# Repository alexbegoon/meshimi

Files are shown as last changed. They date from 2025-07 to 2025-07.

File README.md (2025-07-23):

<div align="center" markdown="1">

<h1>Meshimi</h1>

<b>Open Hardware & Open Source Multi-Protocol Wireless Module</b>

</div>

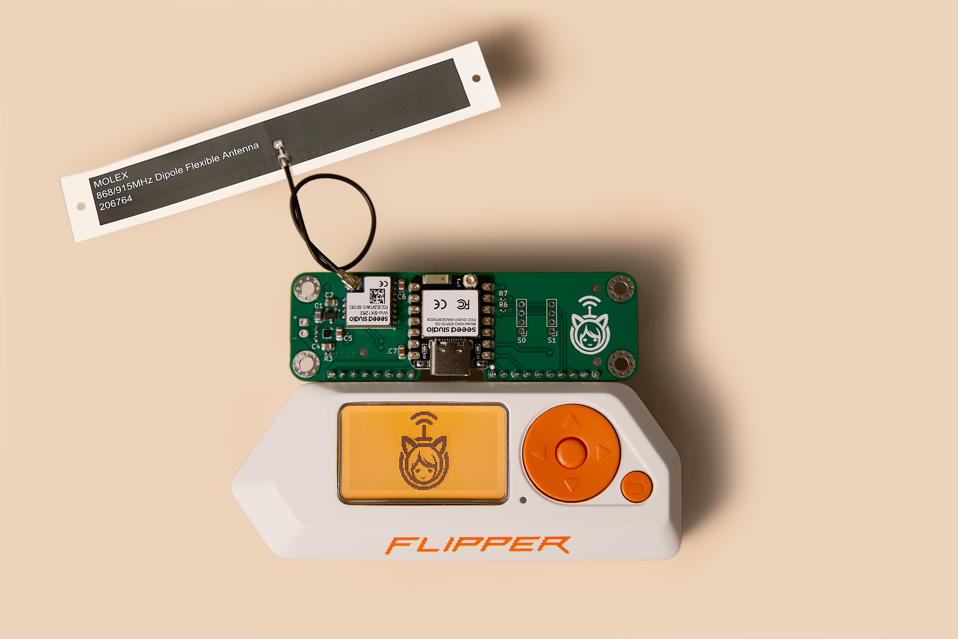
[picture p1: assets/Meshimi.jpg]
Meshimi


Meshimi empowers your Flipper Zero with advanced mesh networking capabilities, utilizing Meshtastic, LoRaWAN, WiFi6 and Bluetooth protocols.



## 📁 Repository Structure
- [`hardware/`](hardware) - PCB schematics, layouts, and production files
- [`mechanical/`](mechanical) - 3D models, enclosures, and assembly guides
- [`firmware/`](firmware) - Core firmware and code examples
- [`software/`](software) - Flipper Zero app and configuration tools
- [`documentation/`](documentation) - Documentation, guides, and certifications
- [`assets/`](assets) - Logos, photos, and marketing materials

## 📖 Documentation

### 🛡️ Certifications
Meshimi project utilizes pre-certified RF modules to ensure regulatory compliance. 
The corresponding CE, FCC, and other certification documentation for these modules are available 
in the [certifications](documentation/certifications) directory. 

We are committed to maintaining full regulatory compliance.

_Seeed XIAO ESP32-C6 module_ is used in Meshimi, which has the following certifications:

1. [Seeed-XIAO-ESP32C6-CE-Verification.pdf](documentation/certifications/Seeed-XIAO-ESP32C6-CE-Verification.pdf)

2. [Seeed-XIAO-ESP32C6-EU-Declaration.pdf](documentation/certifications/Seeed-XIAO-ESP32C6-EU-Declaration.pdf)

3. [Seeed-XIAO-ESP32C6-FCC-Declaration.pdf](documentation/certifications/Seeed-XIAO-ESP32C6-FCC-Declaration.pdf)

4. [Seeed-XIAO-ESP32C6-TELEC-Certificate.pdf](documentation/certifications/Seeed-XIAO-ESP32C6-TELEC-Certificate.pdf)

5. [Seeed-XIAO-ESP32C6-UK-Declaration.pdf](documentation/certifications/Seeed-XIAO-ESP32C6-UK-Declaration.pdf)

6. [Seeed-XIAO-Series-RoHS-Certificate.pdf](documentation/certifications/Seeed-XIAO-Series-RoHS-Certificate.pdf)

_Seeed Wio SX-1262 module_ is used in Meshimi, which has the following certifications:

1. [Seeed-Wio-SX1262-CE-Verification.pdf](documentation/certifications/Seeed-Wio-SX1262-CE-Verification.pdf)

2. [Seeed-Wio-SX1262-EU-Declaration.pdf](documentation/certifications/Seeed-Wio-SX1262-EU-Declaration.pdf)

3. [Seeed-Wio-SX1262-FCC-Authorization.pdf](documentation/certifications/Seeed-Wio-SX1262-FCC-Authorization.pdf)

4. [Seeed-Wio-SX1262-TELEC-Certificate.pdf](documentation/certifications/Seeed-Wio-SX1262-TELEC-Certificate.pdf)

5. [Seeed-Wio-SX1262-UK-Declaration.pdf](documentation/certifications/Seeed-Wio-SX1262-UK-Declaration.pdf)

6. [Seeed-Wio-SX1262-RoHS-Certificate.pdf](documentation/certifications/Seeed-Wio-SX1262-RoHS-Certificate.pdf)

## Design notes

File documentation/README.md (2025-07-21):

## Documentation

#### Index
1. [Enclosures for the Meshimi Module](enclosure.md)
2. [Flipper Zero user guide](flipper.md)

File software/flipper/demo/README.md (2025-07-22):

# Meshimi

Meshimi unlocks powerful mesh networking for your [Flipper Zero](https://flipperzero.one/) combining [Meshtastic](https://meshtastic.org/), [LoRaWAN](https://lora-alliance.org/about-lorawan/) and other protocols like [Matter](https://developers.home.google.com/matter/overview) and [Thread](https://www.threadgroup.org/What-is-Thread/Overview) to give you rock‑solid connectivity across miles, even off‑grid.

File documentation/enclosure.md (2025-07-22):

## Enclosures for the Meshimi Module



### Design with Built-in Antenna

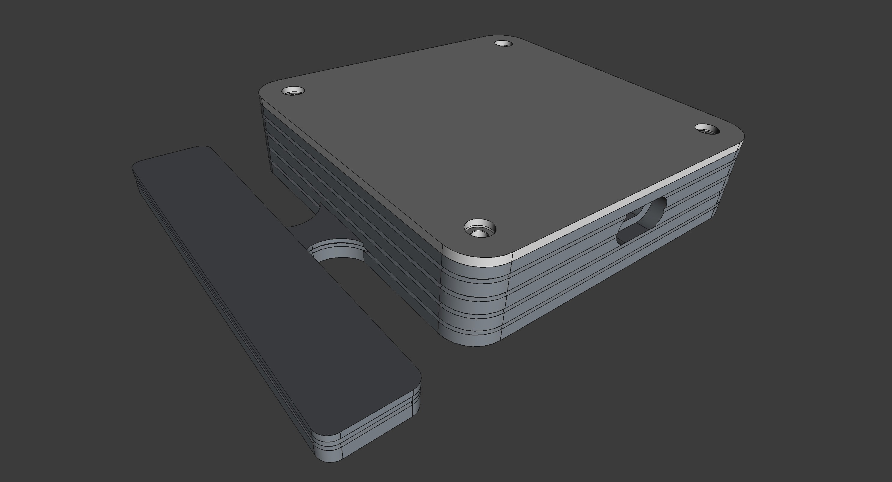
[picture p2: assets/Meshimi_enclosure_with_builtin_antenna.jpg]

Step file: [Meshimi_enclosure_with_builtin_antenna.step](../mechanical/enclosure/Meshimi_enclosure_with_builtin_antenna.step)

Optimized for 3D FDM printing, this enclosure is designed to accommodate the Meshimi module with an integrated antenna.

### Design with External Antenna

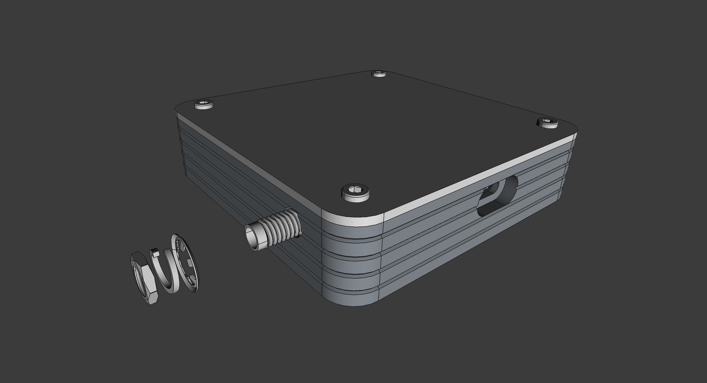
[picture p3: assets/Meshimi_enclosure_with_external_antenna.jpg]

Step file: [Meshimi_enclosure_with_external_antenna.step](../mechanical/enclosure/Meshimi_enclosure_with_external_antenna.step)

This enclosure, optimized for 3D FDM printing, is designed to house the Meshimi module with an external antenna.

It features an SMA connector for attaching an external antenna, providing flexibility for various use cases and environments.

### Enclosure Assembly Guide

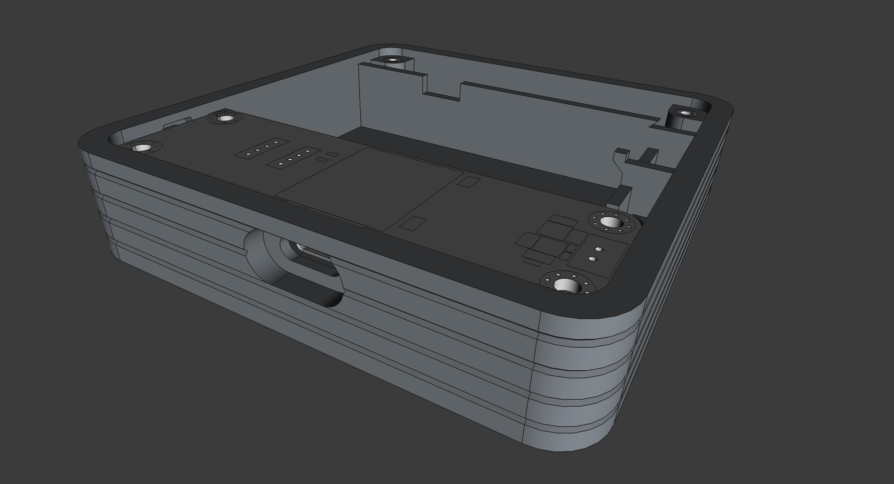
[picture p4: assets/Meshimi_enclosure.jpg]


This enclosure is designed to house the Meshimi module and can be assembled by following these steps:
1. **Print the Enclosure**: Use a 3D printer to fabricate the enclosure files provided in the [enclosure](../mechanical/enclosure) directory.
2. **Insert Brass Heat Inserts**: Place brass heat inserts into the designated holes in the enclosure.
3. **Attach the Meshimi Module**: Secure the Meshimi module inside the enclosure using screws.

[//]: # (TODO: Improve the assembly guide with more detailed instructions and images.)

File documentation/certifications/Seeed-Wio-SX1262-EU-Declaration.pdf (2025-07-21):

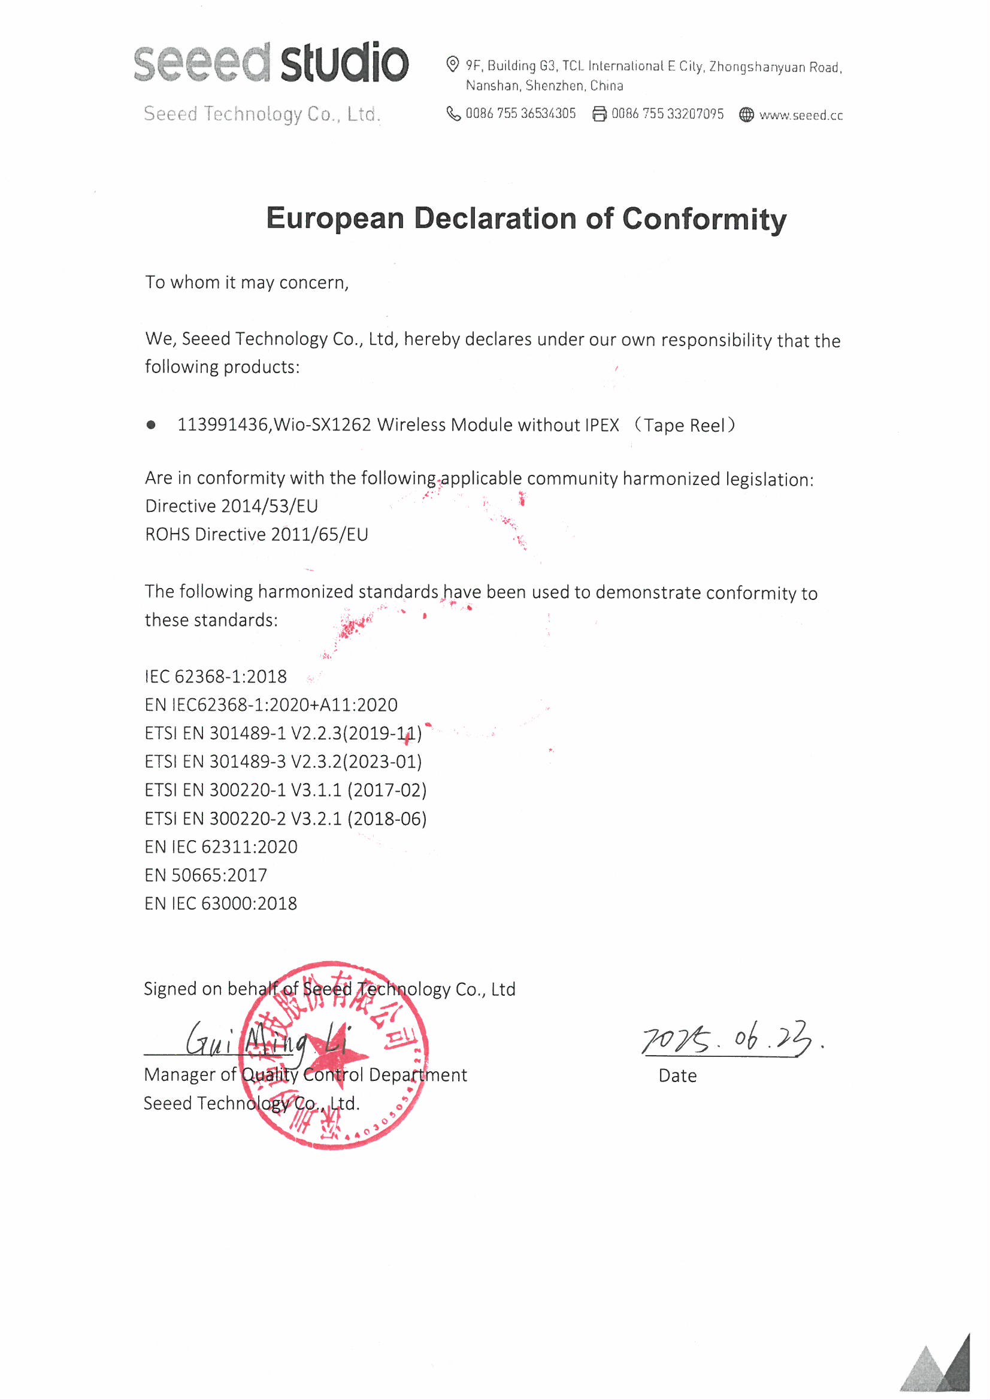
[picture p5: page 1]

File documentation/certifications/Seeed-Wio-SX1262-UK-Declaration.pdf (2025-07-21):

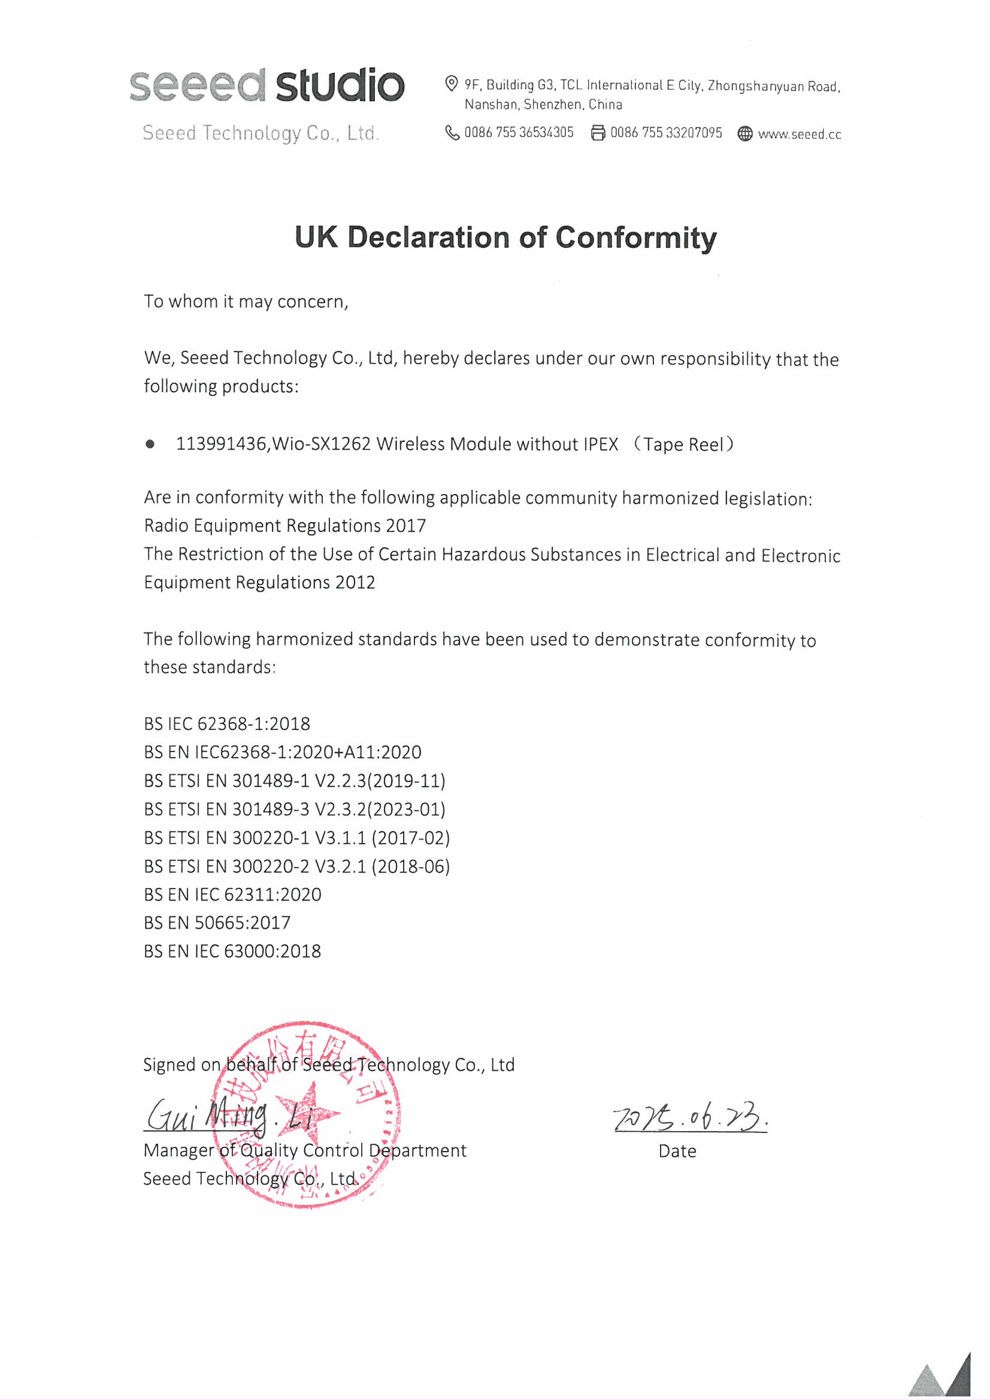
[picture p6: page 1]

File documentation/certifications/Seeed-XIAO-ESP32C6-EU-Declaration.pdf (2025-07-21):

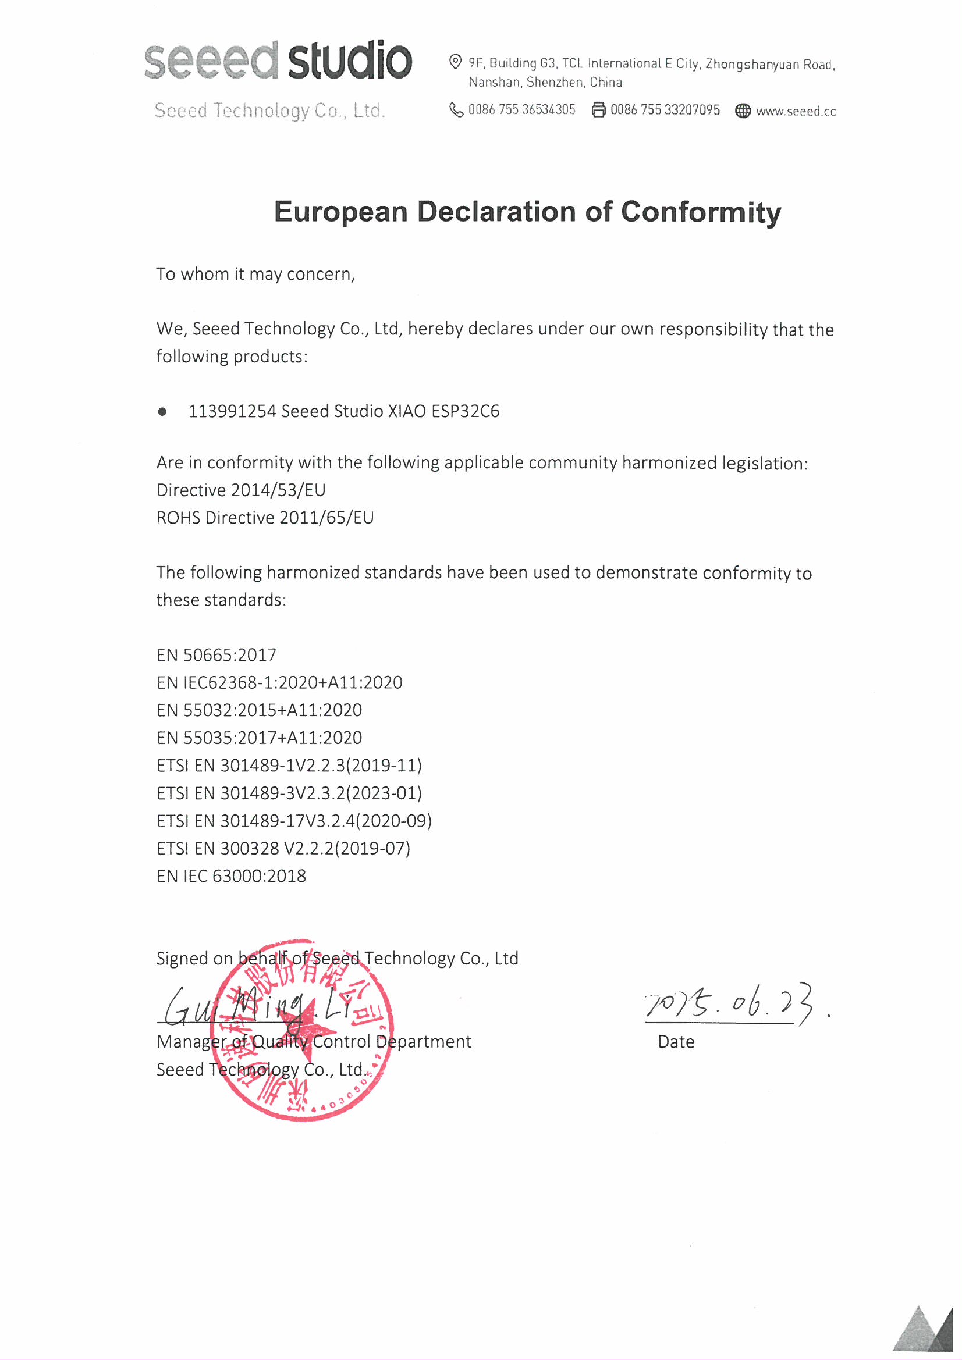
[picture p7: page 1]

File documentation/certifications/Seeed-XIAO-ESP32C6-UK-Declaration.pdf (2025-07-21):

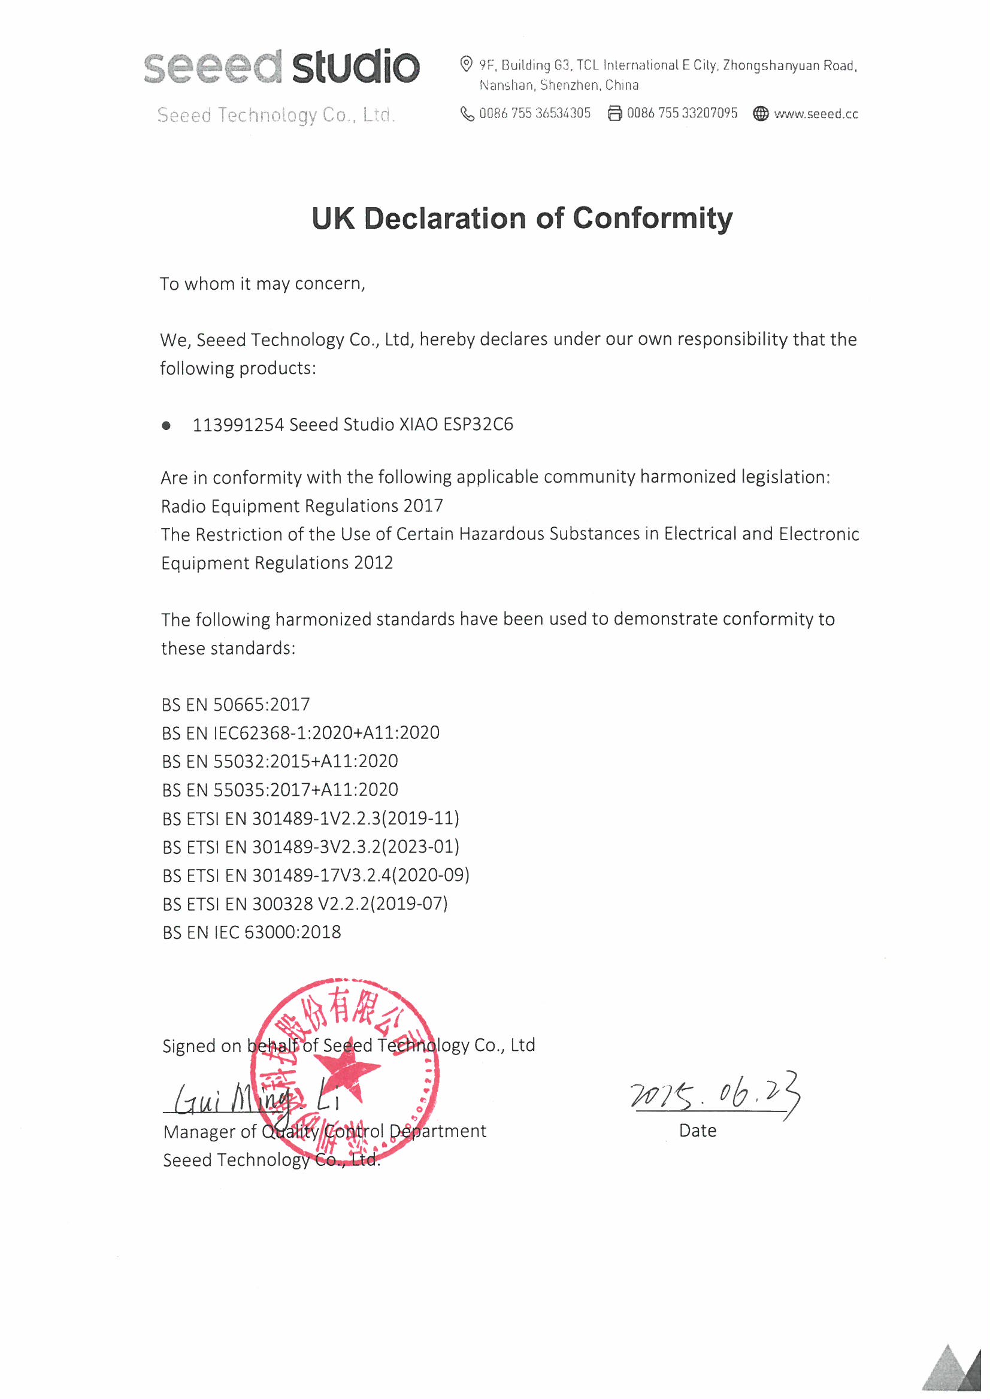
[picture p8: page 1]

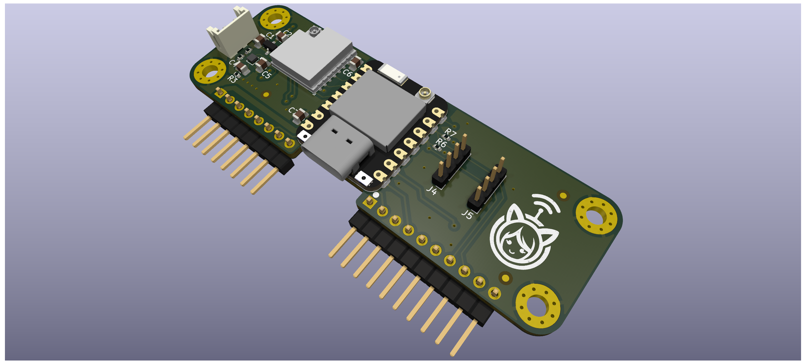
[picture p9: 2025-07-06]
hardware/v1.0/Meshimi.png

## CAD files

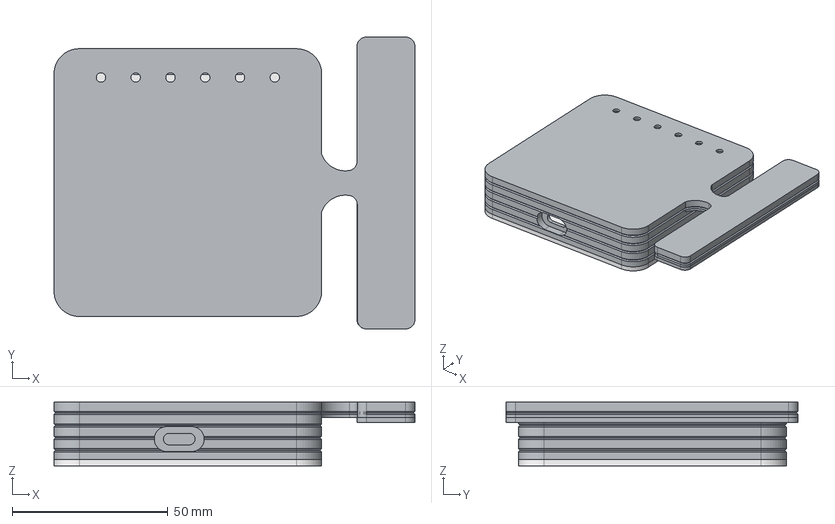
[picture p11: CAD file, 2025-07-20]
mechanical/enclosure/Meshimi_enclosure_with_builtin_antenna.step
115.7 x 93.6 x 20.5 mm
Case
Antenna_lid
Lid

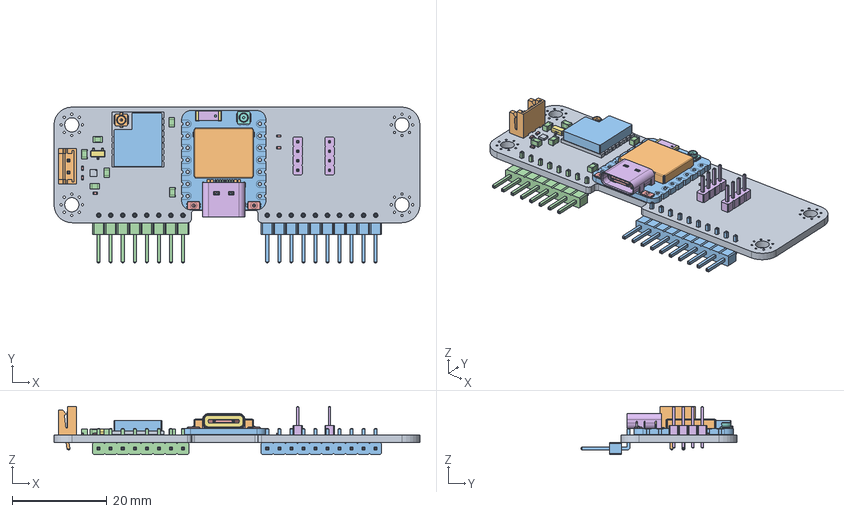
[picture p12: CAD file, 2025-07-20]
mechanical/Meshimi_PCB.step
77.2 x 32.9 x 10.1 mm
PCB
Modules
Components

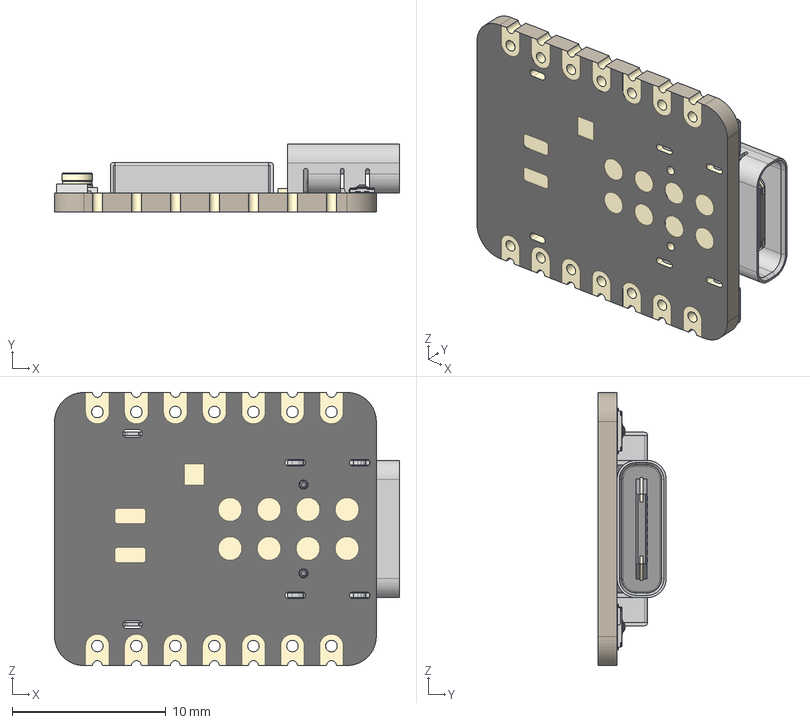
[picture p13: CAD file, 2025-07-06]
mechanical/models/Seeed Studio XIAO ESP32-C6.step
22.5 x 4.46 x 17.8 mm
BOSS-EXTRUDE14_8_
BOSS-EXTRUDE7_4_
BOSS-EXTRUDE7_3_
BOSS-EXTRUDE14_4_
BOSS-EXTRUDE14_2_
BOSS-EXTRUDE14_11_
BOSS-EXTRUDE7_7_
BOSS-EXTRUDE14_9_
BOSS-EXTRUDE14_3_
BOSS-EXTRUDE14_7_
MIRROR2
BOSS-EXTRUDE14_5_
BOSS-EXTRUDE14_12_
BOSS-EXTRUDE7_8_
BOSS-EXTRUDE7_1_
BOSS-EXTRUDE14_10_
BOSS-EXTRUDE7_9_
BOSS-EXTRUDE14_6_
BOSS-EXTRUDE14_1_
BOSS-EXTRUDE7_6_
BOSS-EXTRUDE7_2_
CUT-EXTRUDE5
BOSS-EXTRUDE7_5_
U.FL Connector v1
Shield
SKTAAAE010 x 2
KH5220-A36 (Ceramic Antenna) v2

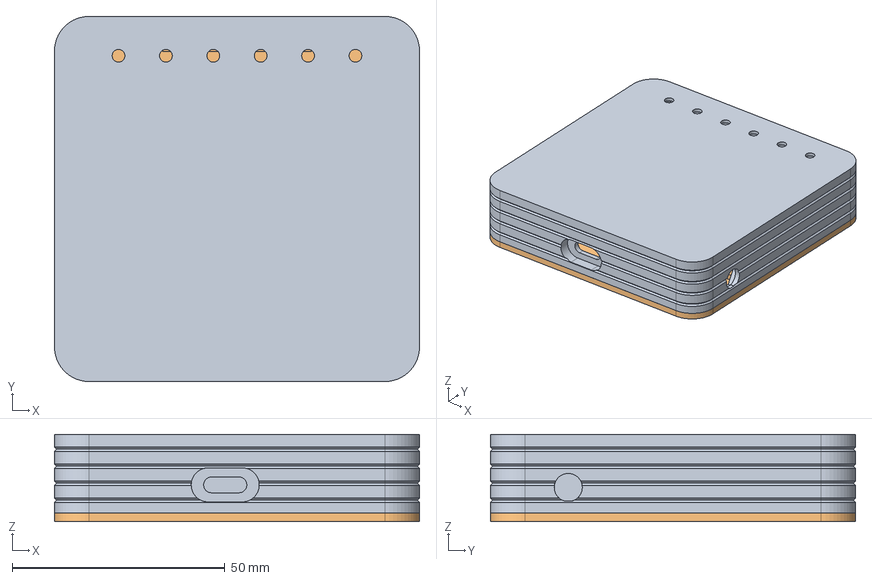
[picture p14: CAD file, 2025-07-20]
mechanical/enclosure/Meshimi_enclosure_with_external_antenna.step
85.8 x 85.9 x 20.5 mm
Case
Lid

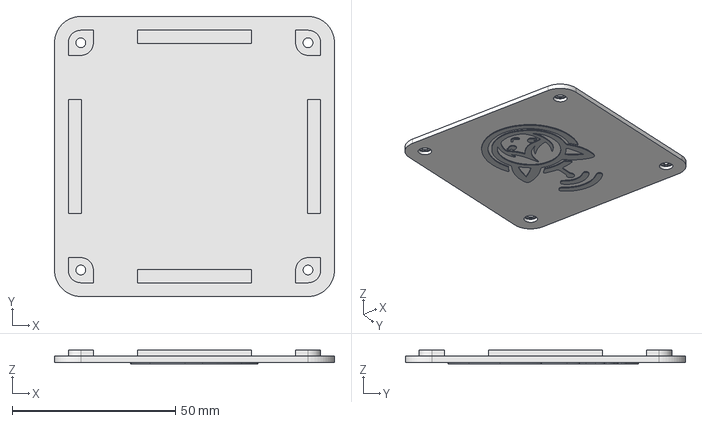
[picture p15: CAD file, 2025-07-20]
mechanical/enclosure/Meshimi_lid_with_logo.step
85.8 x 85.9 x 4.20 mm
Lid
Logo

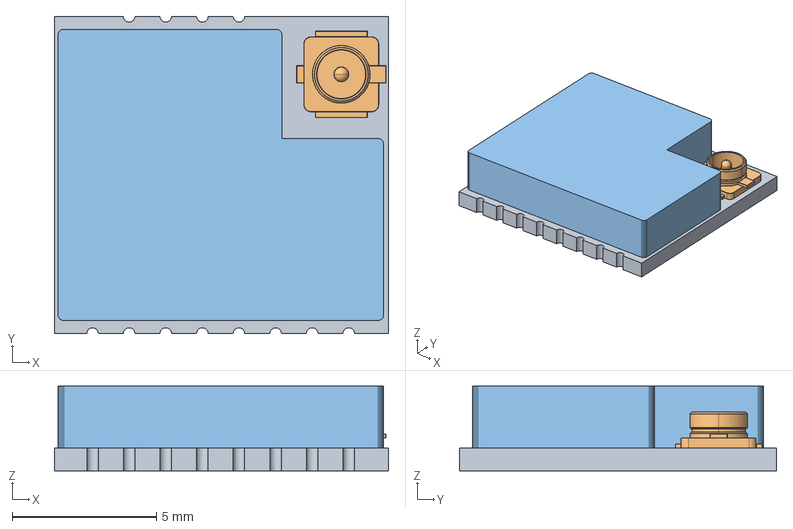
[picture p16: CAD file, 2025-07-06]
mechanical/models/wio-sx1262.step
11.6 x 11.0 x 2.95 mm

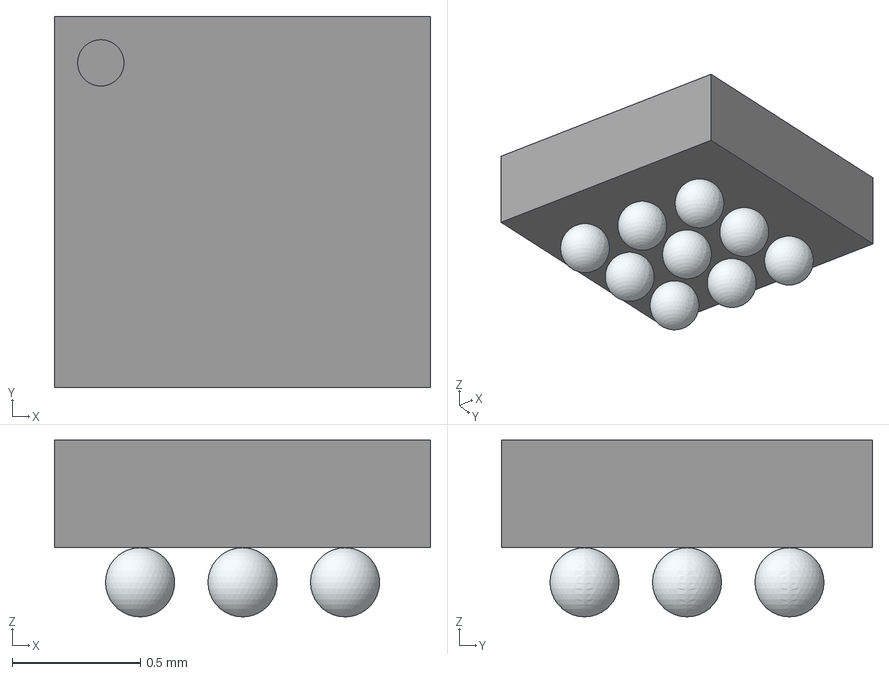
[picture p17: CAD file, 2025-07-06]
mechanical/models/MAX17261MEWL+T.stp
1.47 x 1.45 x 0.69 mm

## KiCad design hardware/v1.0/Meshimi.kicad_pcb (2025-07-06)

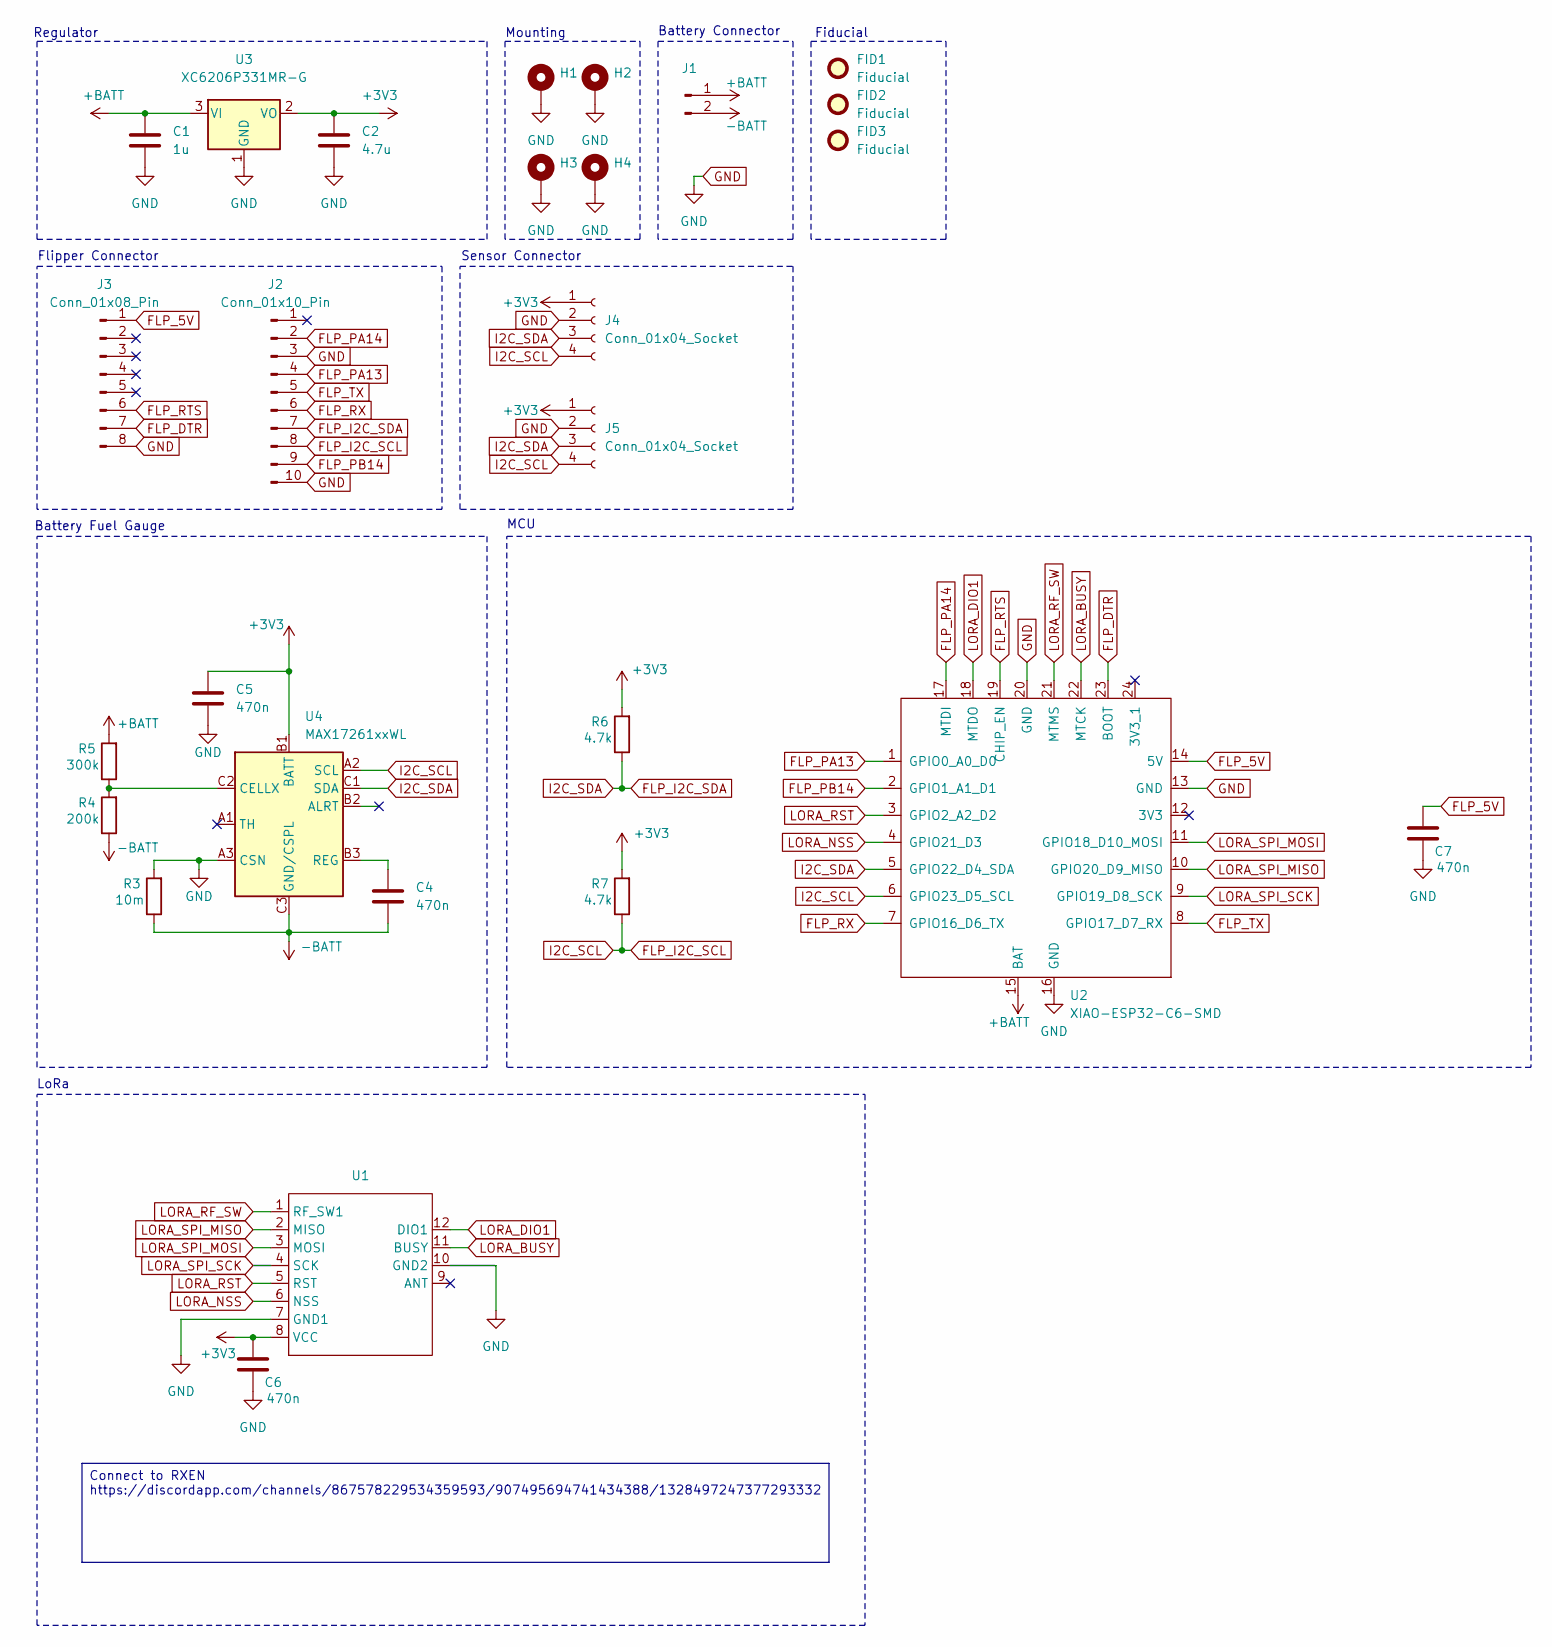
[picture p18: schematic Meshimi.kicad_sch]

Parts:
C1: 1u; C_0805_2012Metric
C2: 4.7u; C_0805_2012Metric
C4, C5, C6, C7: 470n; C_0805_2012Metric
FID1, FID2, FID3: Fiducial; Fiducial_1mm_Mask2mm
H1, H2, H3, H4: MountingHole_3mm_Pad_Via
J1: JST_EH_B2B-EH-A_1x02_P2.50mm_Vertical
J2: Conn_01x10_Pin; PinHeader_1x10_P2.54mm_Horizontal
J3: Conn_01x08_Pin; PinHeader_1x08_P2.54mm_Horizontal
J4, J5: Conn_01x04_Socket; PinHeader_1x04_P2.00mm_Vertical
R3: 10m; R_0402_1005Metric
R4: 200k; R_0402_1005Metric
R5: 300k; R_0402_1005Metric
R6, R7: 4.7k; R_0402_1005Metric
U1: Wio-SX1262
U2: XIAO-ESP32-C6-SMD; XIAO-ESP32C6-SMD
U3: XC6206P331MR-G; SOT-23
U4: MAX17261xxWL; Maxim_WLP-9_1.595x1.415_Layout3x3_P0.4mm_Ball0.27mm_Pad0.25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

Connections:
+3V3: C2.1, C5.1, C6.1, J4.1, J5.1, R6.2, R7.2, U1.8 (VCC), U3.2 (VO), U4.B1 (BATT)
+BATT: C1.1, J1.1, R5.2, U2.15 (BAT), U3.3 (VI)
-BATT: C4.2, J1.2, R3.1, R4.1, U4.C3 (GND/CSPL)
FLP_5V: C7.1, J3.1, U2.14 (5V)
FLP_DTR: J3.7, U2.23 (BOOT)
FLP_I2C_SCL: J2.8, J4.4, J5.4, R7.1, U2.6 (GPIO23_D5_SCL), U4.A2 (SCL)
FLP_I2C_SDA: J2.7, J4.3, J5.3, R6.1, U2.5 (GPIO22_D4_SDA), U4.C1 (SDA)
FLP_PA13: J2.4, U2.1 (GPIO0_A0_D0)
FLP_PA14: J2.2, U2.17 (MTDI)
FLP_PB14: J2.9, U2.2 (GPIO1_A1_D1)
FLP_RTS: J3.6, U2.19 (CHIP_EN)
FLP_RX: J2.6, U2.7 (GPIO16_D6_TX)
FLP_TX: J2.5, U2.8 (GPIO17_D7_RX)
GND: C1.2, C2.2, C5.2, C6.2, C7.2, H1.1, H2.1, H3.1, H4.1, J2.3, J2.10, J3.8, J4.2, J5.2, R3.2, U1.7 (GND1), U1.10 (GND2), U2.13 (GND), U2.16 (GND), U2.20 (GND), U3.1 (GND), U4.A3 (CSN)
LORA_BUSY: U1.11 (BUSY), U2.22 (MTCK)
LORA_DIO1: U1.12 (DIO1), U2.18 (MTDO)
LORA_NSS: U1.6 (NSS), U2.4 (GPIO21_D3)
LORA_RF_SW: U1.1 (RF_SW1), U2.21 (MTMS)
LORA_RST: U1.5 (RST), U2.3 (GPIO2_A2_D2)
LORA_SPI_MISO: U1.2 (MISO), U2.10 (GPIO20_D9_MISO)
LORA_SPI_MOSI: U1.3 (MOSI), U2.11 (GPIO18_D10_MOSI)
LORA_SPI_SCK: U1.4 (SCK), U2.9 (GPIO19_D8_SCK)
unnamed: R4.2, R5.1, U4.C2 (CELLX)
unnamed: C4.1, U4.B3 (REG)

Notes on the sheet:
MCU
Flipper Connector
Mounting
Battery Fuel Gauge
Sensor Connector
LoRa
Regulator
Battery Connector
Fiducial
Connect to RXEN https://discordapp.com/channels/867578229534359593/907495694741434388/1328497247377293332

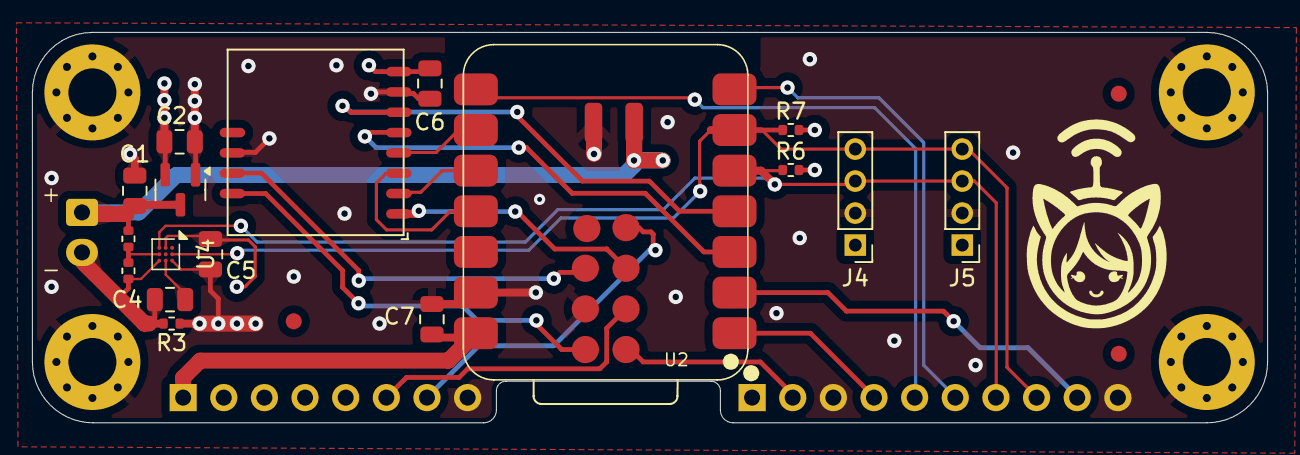
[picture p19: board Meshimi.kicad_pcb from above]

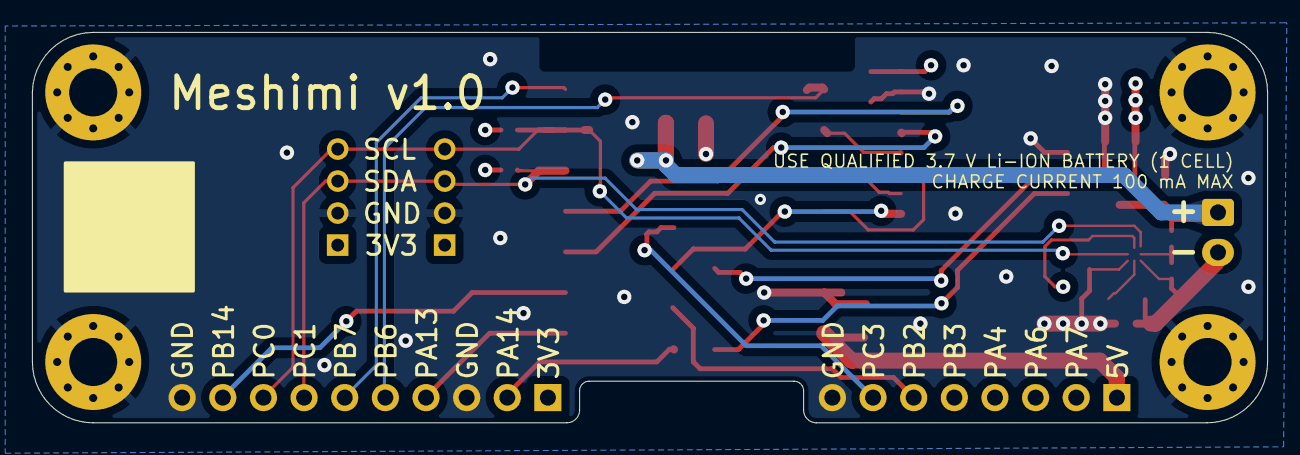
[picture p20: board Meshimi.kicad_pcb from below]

Board: 4 copper layers, 77.2 x 24.4 mm, 27 parts (2 on the bottom side), 24 nets.

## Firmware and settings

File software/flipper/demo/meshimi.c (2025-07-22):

#include "meshimi.h"
#include <furi_hal_serial.h>

// UART Configuration
#define RX_BUF_SIZE 256
#define UART_BAUD_RATE 115200
#define LED_NOTIFICATION_COOLDOWN_MS 600

// UART Structure
struct MeshimiUart {
    Meshimi* app;
    FuriThread* rx_thread;
    FuriStreamBuffer* rx_stream;
    uint8_t rx_buf[RX_BUF_SIZE + 1];
    FuriHalSerialHandle* serial_handle;
    uint32_t last_notification_time;  // Added for rate limiting
};

typedef enum {
    WorkerEvtStop = (1 << 0),
    WorkerEvtRxDone = (1 << 1),
} WorkerEvtFlags;

const NotificationMessage message_green_128 = {
    .type = NotificationMessageTypeLedGreen,
    .data.led.value = 0x80,  // 50% brightness
};

const NotificationMessage message_delay_150 = {
    .type = NotificationMessageTypeDelay,
    .data.delay.length = 150,
};

// LED Notification Sequences
const NotificationSequence sequence_blink_uart_led = {
    &message_green_0,
    &message_blue_255,

    &message_delay_150,

    &message_green_128,
    &message_blue_0,

    &message_delay_150,

    &message_green_0,
    &message_blue_255,

    &message_delay_150,

    &message_green_128,
    &message_blue_0,

    &message_delay_150,

    &message_blue_0,
    &message_green_0,
    NULL,
};

// TODO: Move UART code to a dedicated library or file
// UART IRQ Callback
void meshimi_uart_on_irq_cb(
    FuriHalSerialHandle* handle,
    FuriHalSerialRxEvent event,
    void* context) {

    struct MeshimiUart* uart = (struct MeshimiUart*)context;
    if(event == FuriHalSerialRxEventData) {
        uint8_t data = furi_hal_serial_async_rx(handle);
        furi_stream_buffer_send(uart->rx_stream, &data, 1, 0);
        furi_thread_flags_set(furi_thread_get_id(uart->rx_thread), WorkerEvtRxDone);
    }
}

// UART Worker Thread
static int32_t meshimi_uart_worker(void* context) {
    struct MeshimiUart* uart = (struct MeshimiUart*)context;

    while(1) {
        uint32_t events = furi_thread_flags_wait(
            WorkerEvtStop | WorkerEvtRxDone,
            FuriFlagWaitAny,
            FuriWaitForever
        );

        furi_check((events & FuriFlagError) == 0);

        if(events & WorkerEvtStop) break;

        if(events & WorkerEvtRxDone) {
            size_t len = furi_stream_buffer_receive(uart->rx_stream, uart->rx_buf, RX_BUF_SIZE, 0);
            if(len > 0) {
                // Null terminate the received data
                uart->rx_buf[len] = '\0';

                // Blink LED when data is received, but rate limit to prevent excessive blinking
                if(uart->app && uart->app->notifications) {
                    uint32_t current_time = furi_get_tick();
                    uint32_t time_since_last = current_time - uart->last_notification_time;

                    // Only send notification if enough time has passed since the last one
                    if(time_since_last >= furi_ms_to_ticks(LED_NOTIFICATION_COOLDOWN_MS)) {
                        notification_message(uart->app->notifications, &sequence_blink_uart_led);
                        uart->last_notification_time = current_time;
                    }
                }

                // Log the received data
                FURI_LOG_D("UART", "Received %zu bytes: %s", len, uart->rx_buf);
            }
        }
    }

    furi_stream_buffer_free(uart->rx_stream);
    return 0;
}

// Initialize UART
struct MeshimiUart* meshimi_uart_init(Meshimi* app) {
    struct MeshimiUart* uart = malloc(sizeof(struct MeshimiUart));
    uart->app = app;
    uart->last_notification_time = 0;  // Initialize notification time tracking

    // Initialize stream buffer and thread
    uart->rx_stream = furi_stream_buffer_alloc(RX_BUF_SIZE, 1);
    uart->rx_thread = furi_thread_alloc();
    furi_thread_set_name(uart->rx_thread, "MeshimiUartRxThread");
    furi_thread_set_stack_size(uart->rx_thread, 1024);
    furi_thread_set_context(uart->rx_thread, uart);
    furi_thread_set_callback(uart->rx_thread, meshimi_uart_worker);
    furi_thread_start(uart->rx_thread);

    // Initialize UART hardware
    uart->serial_handle = furi_hal_serial_control_acquire(FuriHalSerialIdUsart);
    furi_check(uart->serial_handle);
    furi_hal_serial_init(uart->serial_handle, UART_BAUD_RATE);
    furi_hal_serial_async_rx_start(uart->serial_handle, meshimi_uart_on_irq_cb, uart, false);

    return uart;
}

// Free UART Resources
void meshimi_uart_free(struct MeshimiUart* uart) {
    furi_assert(uart);

    furi_hal_serial_async_rx_stop(uart->serial_handle);
    furi_hal_serial_deinit(uart->serial_handle);
    furi_hal_serial_control_release(uart->serial_handle);

    furi_thread_flags_set(furi_thread_get_id(uart->rx_thread), WorkerEvtStop);
    furi_thread_join(uart->rx_thread);
    furi_thread_free(uart->rx_thread);

    free(uart);
}

// Send data via UART
void meshimi_uart_tx(struct MeshimiUart* uart, uint8_t* data, size_t len) {
    if(uart && uart->serial_handle) {
        furi_hal_serial_tx(uart->serial_handle, data, len);
    }
}

// Original callback functions remain unchanged
bool meshimi_custom_event_callback(void* context, uint32_t event) {
    furi_assert(context);
    Meshimi* meshimi = context;
    return scene_manager_handle_custom_event(meshimi->scene_manager, event);
}

bool meshimi_back_event_callback(void* context) {
    furi_assert(context);
    Meshimi* meshimi = context;
    return scene_manager_handle_back_event(meshimi->scene_manager);
}

void meshimi_tick_event_callback(void* context) {
    furi_assert(context);
    Meshimi* meshimi = context;
    scene_manager_handle_tick_event(meshimi->scene_manager);
}
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

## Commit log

2025-07-06 Add initial KiCad project files and configuration
    [MAX17261MEWL+T.stp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]
2025-07-06 Update KiCad project files to version 9.0.2
    [Meshimi-B_Cu.gbl, Meshimi-B_Mask.gbs, Meshimi-B_Paste.gbp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]
2025-07-20 Update .gitignore and add description link in Meshimi schematic
    [Meshimi.kicad_sch]
2025-07-20 Add CAD models: enclosure housing/cover and PCB design
    [Meshimi_PCB.step, Meshimi_enclosure_with_builtin_antenna.step, Meshimi_enclosure_with_external_antenna.step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]
2025-07-20 Add documentation for Meshimi module enclosures and Flipper Zero integration
2025-07-21 Update README.md to enhance certification information and regulatory compliance details
